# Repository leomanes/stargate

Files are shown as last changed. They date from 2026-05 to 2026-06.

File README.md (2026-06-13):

# Stargate MSX Compatible Computer

> [!NOTE]
>**Latest updates:**<br>
>- Version 2.1.3 released<br>
>  -- new onboard amp module+speaker connectors;<br>
>  -- Tang Nano PWM audio connected to the mixer.<br>
>- Kicad files available (Kicad v9.0.2) <br>

Stargate is an MSX compatible computer built using parts that are still available today.

Many original MSX parts are becoming harder to find, more expensive, or counterfeit. Stargate uses a hybrid approach where common parts remain original while rare or unreliable components are replaced with modern alternatives such as the Tang Nano 20K.

The board is a dual layer PCB using 74-series logic, an 8255 PPI, and a real PSG chip. Video is handled by a Tang Nano 20K running a V9958 compatible core. The Z80 is also implemented inside the FPGA.

If you have a soldering iron and some patience, you can probably put it together.

The machine is built around the **[Goauld SD project](https://github.com/jabadiagm/MSXgoauldSD_tn20k)** by Javier Abadia.

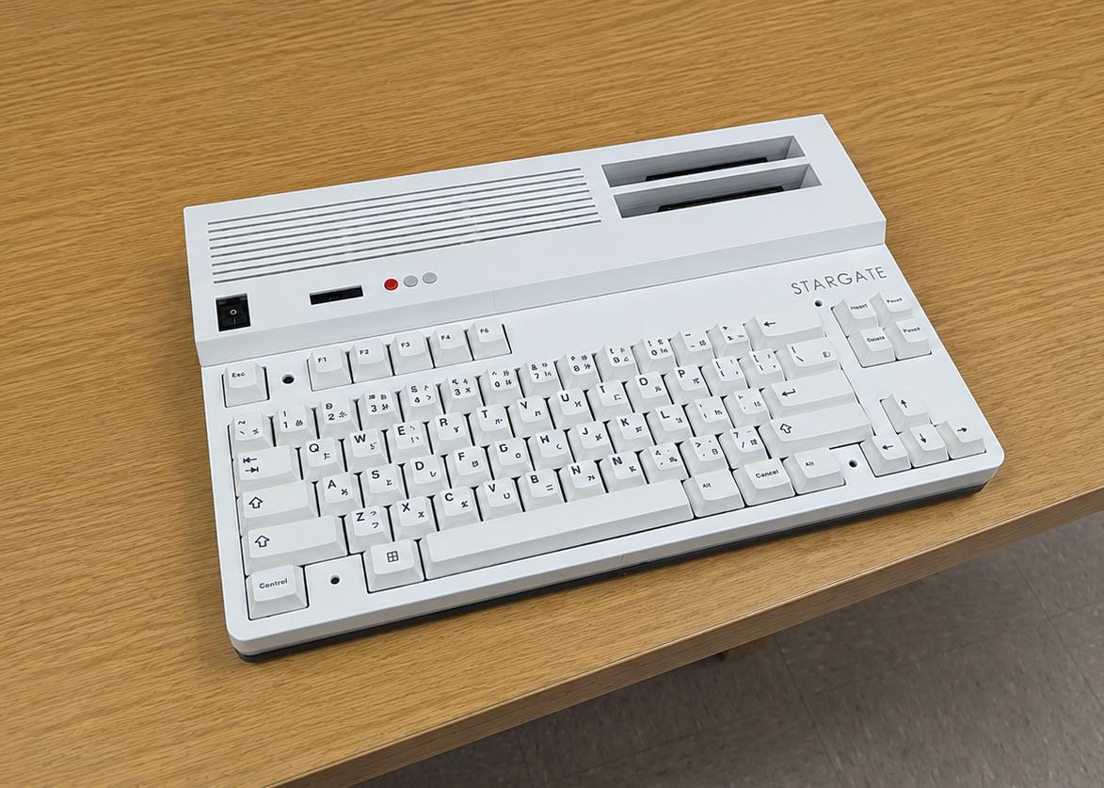
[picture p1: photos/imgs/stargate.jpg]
Stargate

## Selling Stargate

Stargate wasn't built to be a commercial product, but as an open source project, nothing stops you from using it that way. All I ask is that you don't modify the original files in any way.

Do not modify the original files in any way or form.

## Goauld SD project

https://github.com/jabadiagm/MSXgoauldSD_tn20k

## Goauld Core specs

- Z80
- V9958 compatible video with HDMI output
- MSX2+ BIOS
- SD card support with Nextor 2.1
- 4 MB mapper
- 2 MB MegaRAM SCC
- RTC
- PSG
- OPLL
- Kanji Level 1 and 2
- Wi-Fi support using ESP

## Stargate features

- Mechanical keyboard
- OLED display
- Overclocking up to 14 MHz (WIP)
- RGB LED effects
- On-board audio
- Audio output
- Reset button
- USB-C and barrel jack for power
- Two joystick ports
- Two cartridge slots
- USB network printing
- IoT Tasmota integration
- IoT TP-Link HS1xx outlet control

## WIP Daughter Board (Internal/External)

> [!NOTE]
> Additional features are provided through an optional daughter board.<bR>
> WIP (no release date yet).

**Ready:**

- USB printer support
- Ethernet connection
- Bluetooth joystick firmware
- RGB Gaming mode (LEDs react to RGB modded games)

**WIP:**

- Slot 2 expansion with custom cartridge
- USB flash drive support
- USB floppy support
- Fast Wi-Fi
- Bluetooth joystick software (extra buttons mapped to keyboard keys)

> [!NOTE]
> Stargate can be assembled without the extra features as a standard MSX compatible computer.

## GitHub

https://github.com/leomanes/stargate

> [!IMPORTANT]
> Project files will be made available when time permits.

## Open Source projects

- Javier Abadia, MSXgoauldSD_tn20k project — https://github.com/jabadiagm
- NataliaPC, MSXgoauld Settings Menu — https://github.com/nataliapc
- Skoti, JFF Computer — https://github.com/konkotgit
- Sergey Kiselev, Omega Keyboard — https://github.com/skiselev
- Oduvaldo (ducasp), UNAPI Driver — https://github.com/ducasp

## Other references

HARA, konamiman, antoniosi

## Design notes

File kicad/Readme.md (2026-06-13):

**Stargate_v2.1.3.zip**
Gerbers in /version v2.1.3 production/production

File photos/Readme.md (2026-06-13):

# Photos

<!-- Regenerate with: py gen_photos_readme.py -->

<table>
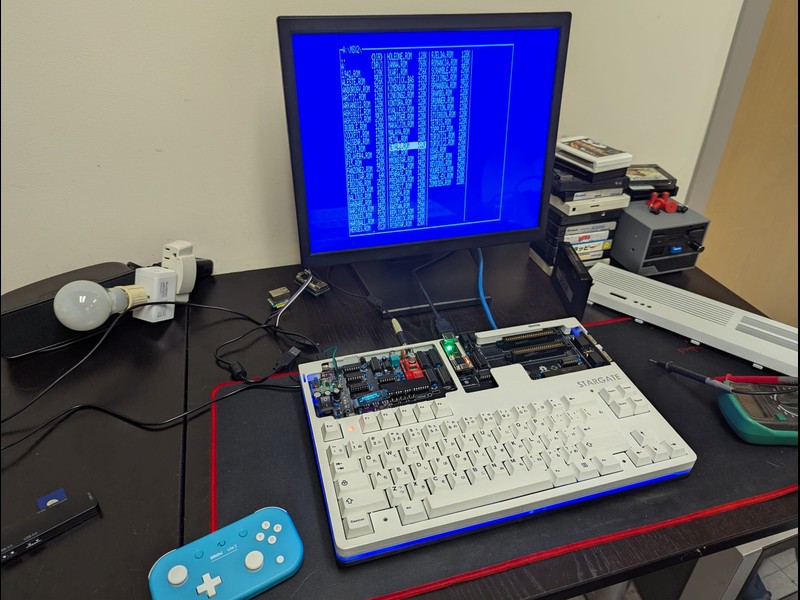
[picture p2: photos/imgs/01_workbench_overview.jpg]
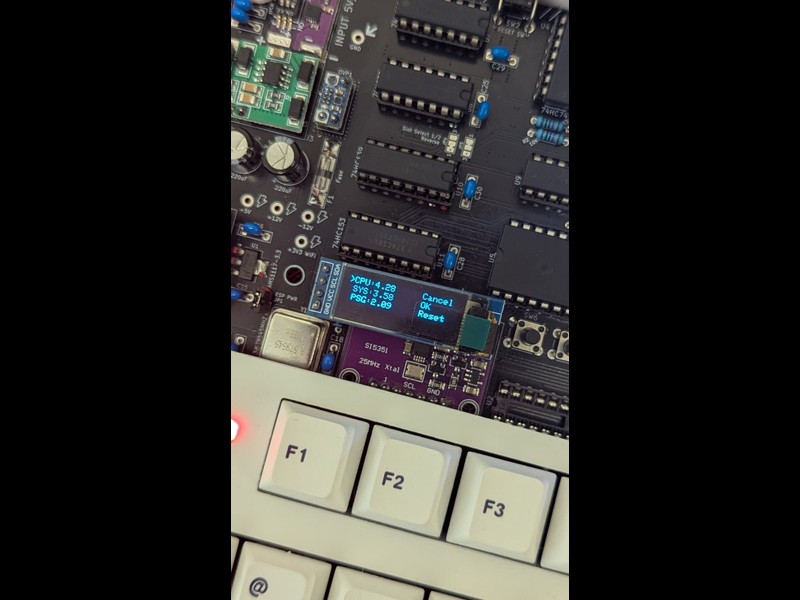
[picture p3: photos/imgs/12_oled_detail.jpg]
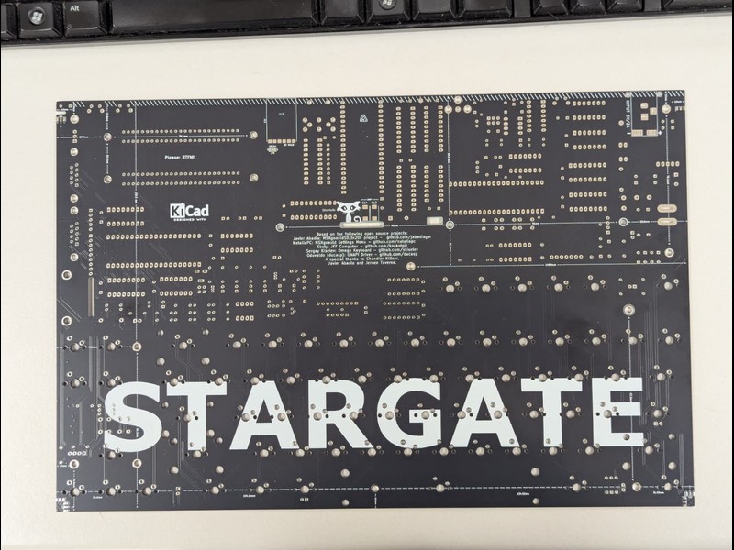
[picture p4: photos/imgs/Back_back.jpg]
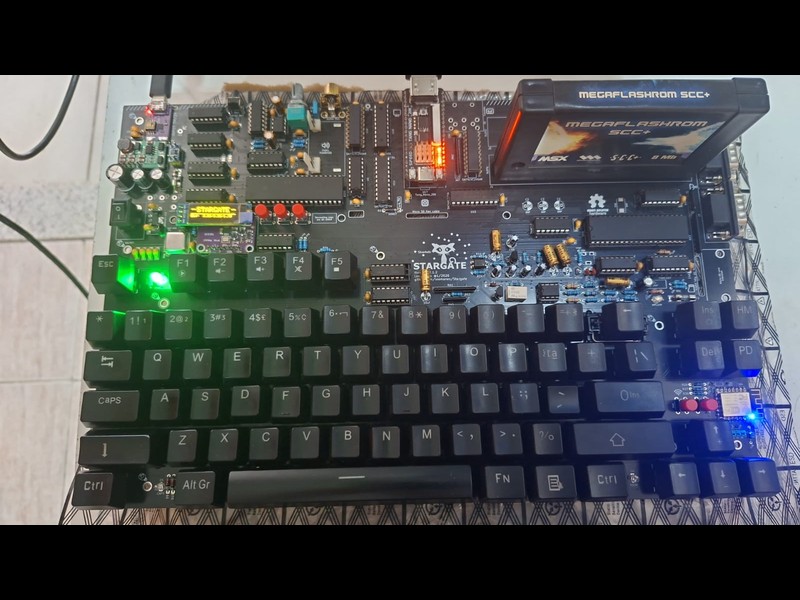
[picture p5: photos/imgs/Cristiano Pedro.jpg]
<tr><td align="center" valign="top"><br><sub>01_workbench_overview.jpg</sub></td><td align="center" valign="top"><br><sub>12_oled_detail.jpg</sub></td><td align="center" valign="top"><br><sub>Back_back.jpg</sub></td><td align="center" valign="top"><br><sub>Cristiano Pedro.jpg</sub></td></tr>
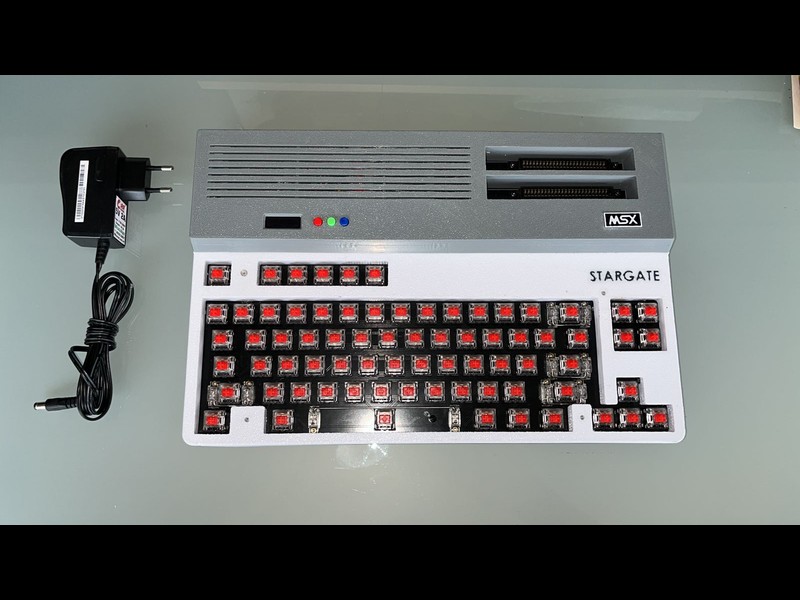
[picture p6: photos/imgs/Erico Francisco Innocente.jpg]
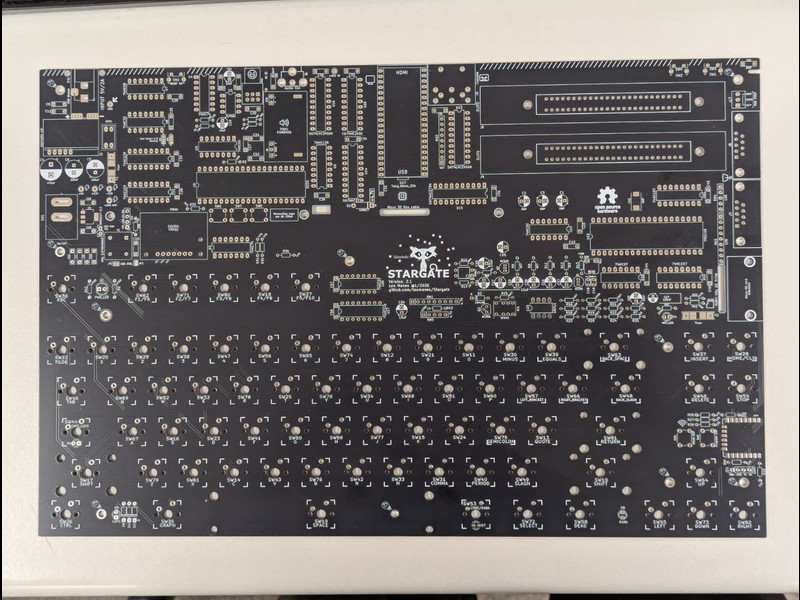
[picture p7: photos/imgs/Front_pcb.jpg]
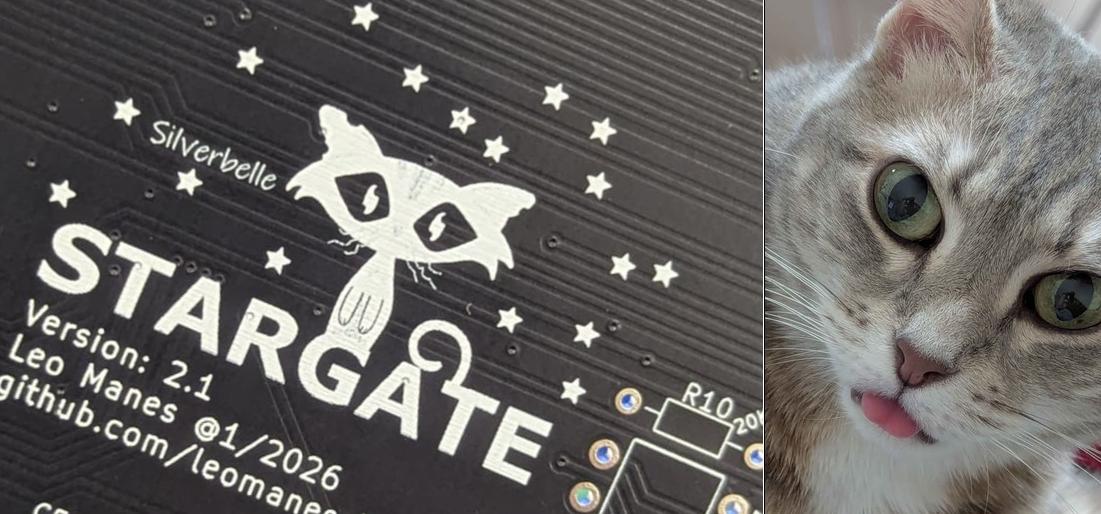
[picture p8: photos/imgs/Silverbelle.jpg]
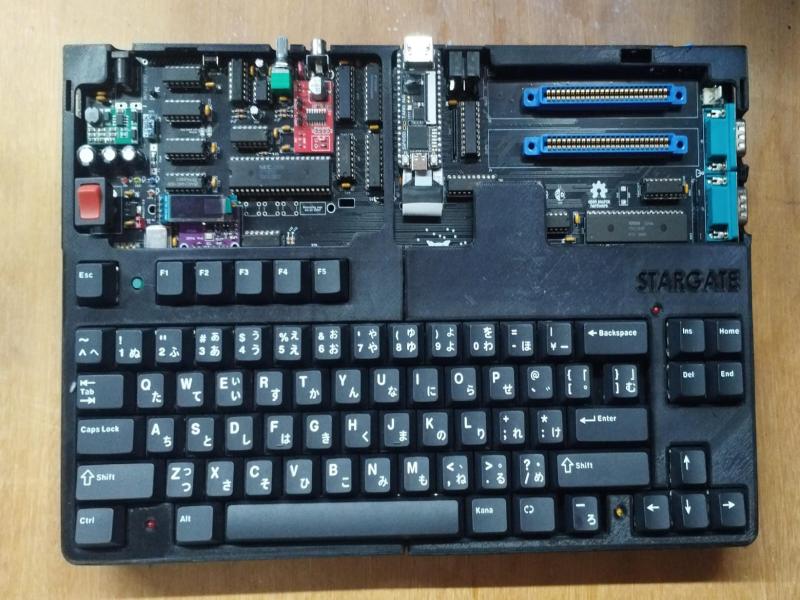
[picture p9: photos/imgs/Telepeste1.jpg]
<tr><td align="center" valign="top"><br><sub>Erico Francisco Innocente.jpg</sub></td><td align="center" valign="top"><br><sub>Front_pcb.jpg</sub></td><td align="center" valign="top"><br><sub>Silverbelle.jpg</sub></td><td align="center" valign="top"><br><sub>Telepeste1.jpg</sub></td></tr>
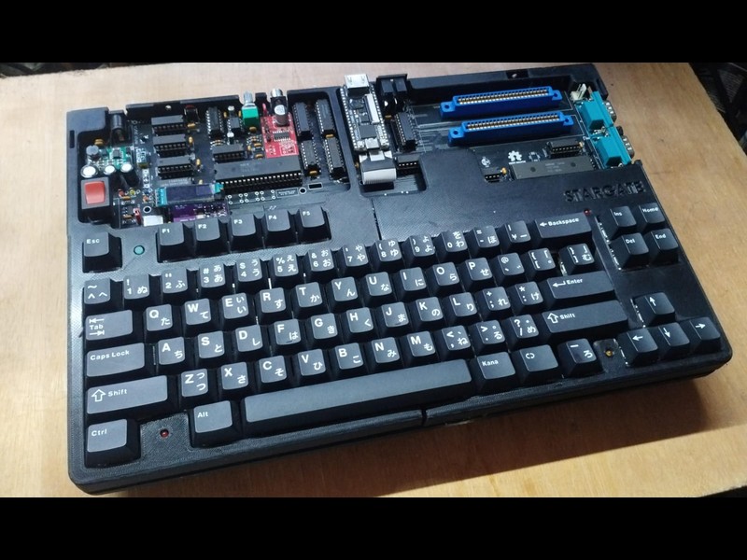
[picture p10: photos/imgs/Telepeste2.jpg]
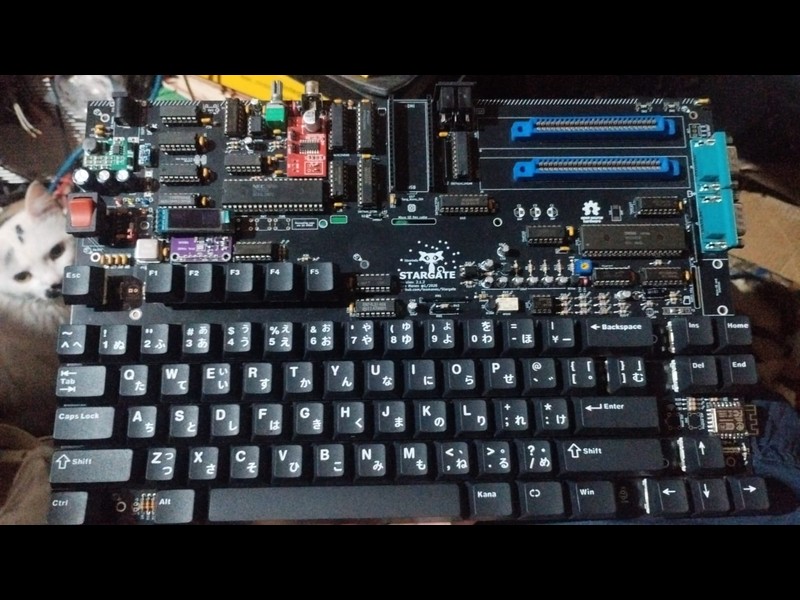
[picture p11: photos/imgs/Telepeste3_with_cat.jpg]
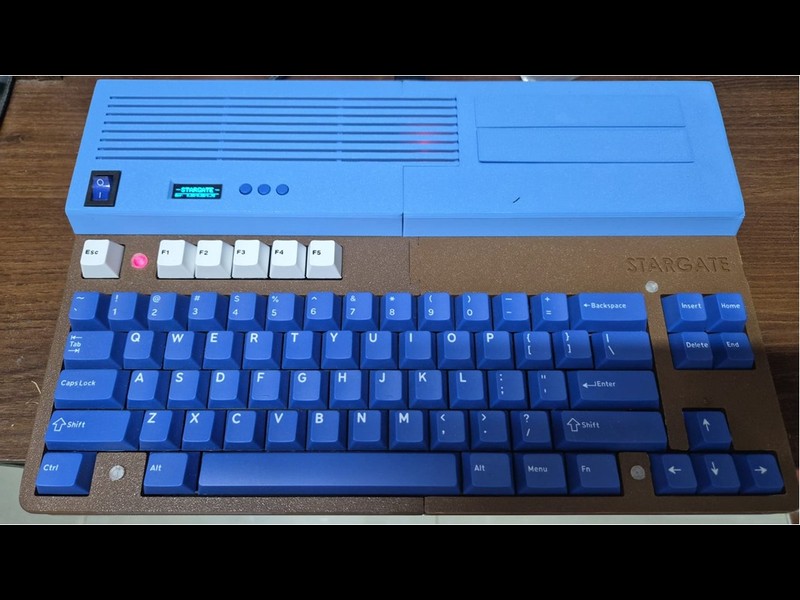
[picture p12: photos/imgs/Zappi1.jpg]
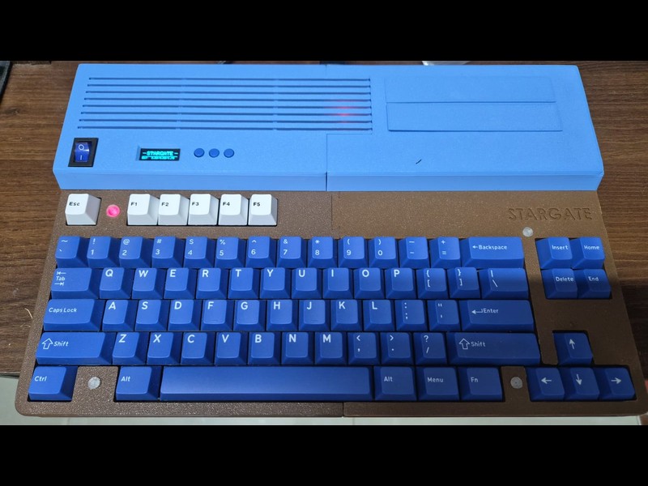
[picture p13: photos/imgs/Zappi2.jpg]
<tr><td align="center" valign="top"><br><sub>Telepeste2.jpg</sub></td><td align="center" valign="top"><br><sub>Telepeste3_with_cat.jpg</sub></td><td align="center" valign="top"><br><sub>Zappi1.jpg</sub></td><td align="center" valign="top"><br><sub>Zappi2.jpg</sub></td></tr>
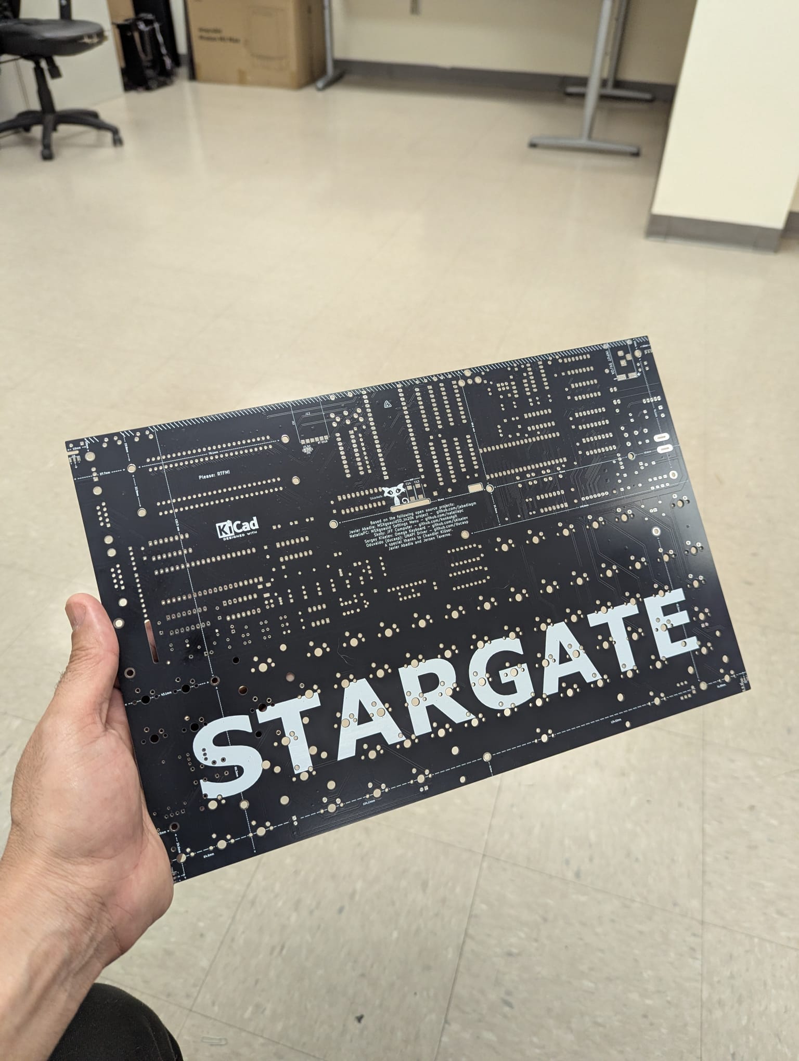
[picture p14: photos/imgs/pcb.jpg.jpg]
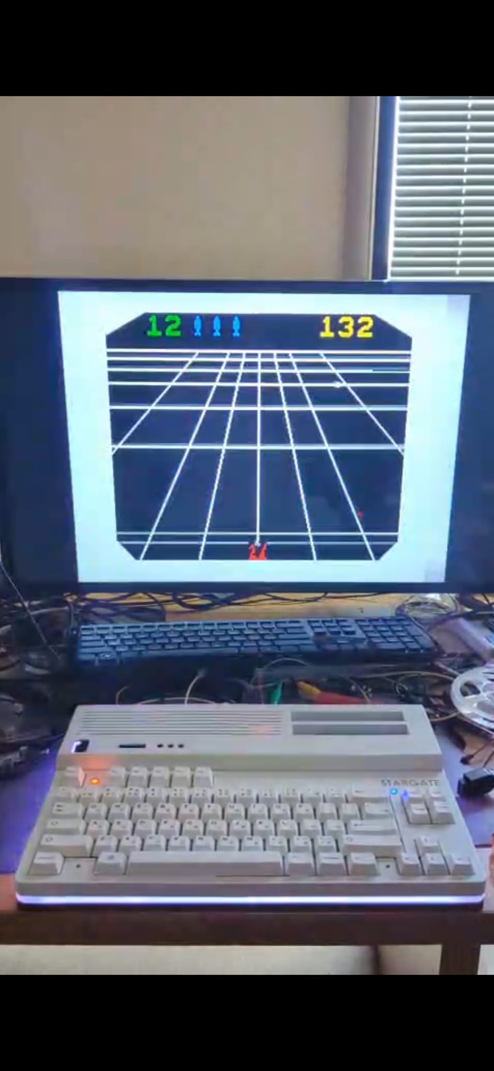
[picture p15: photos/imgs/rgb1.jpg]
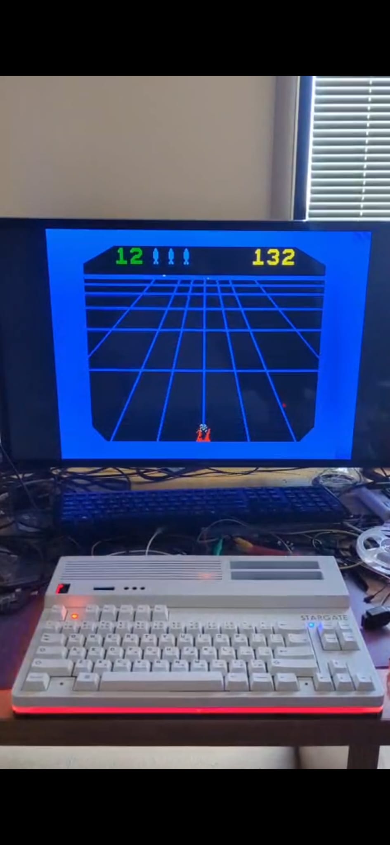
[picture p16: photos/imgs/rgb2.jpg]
<tr><td align="center" valign="top"><br><sub>pcb.jpg.jpg</sub></td><td align="center" valign="top"><br><sub>rgb1.jpg</sub></td><td align="center" valign="top"><br><sub>rgb2.jpg</sub></td><td align="center" valign="top"><br><sub>stargate.jpg</sub></td></tr>
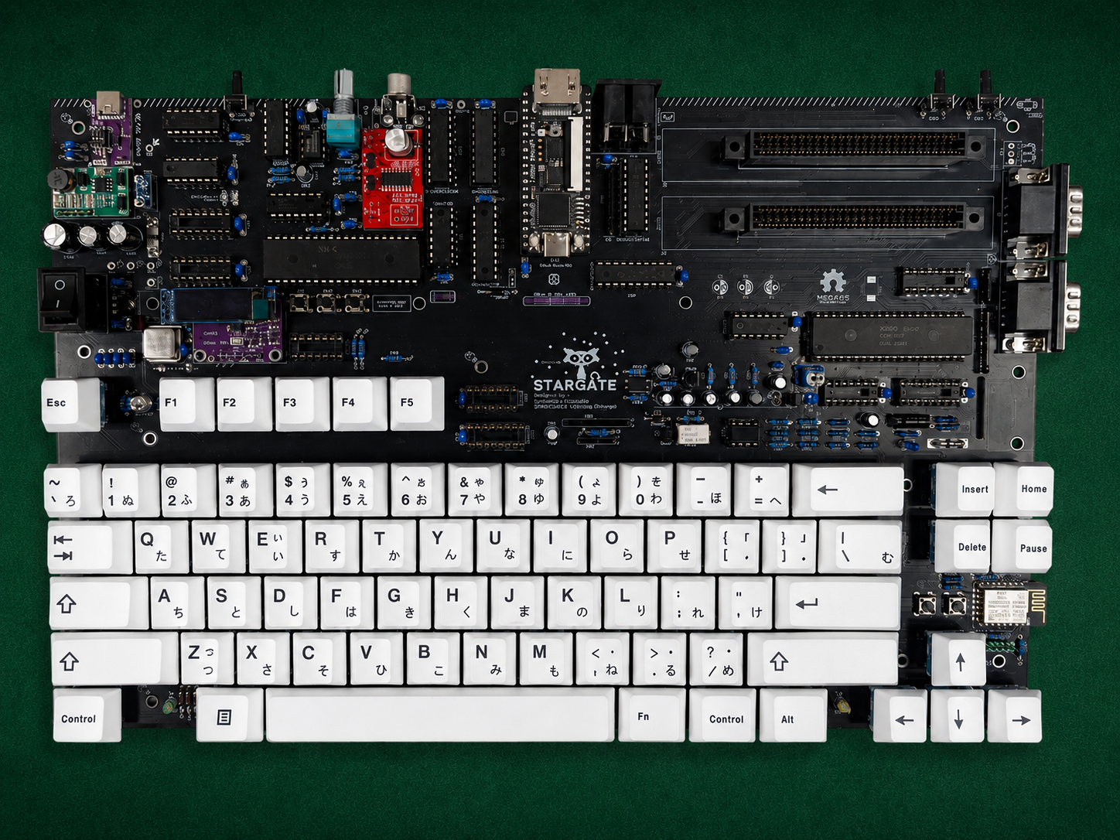
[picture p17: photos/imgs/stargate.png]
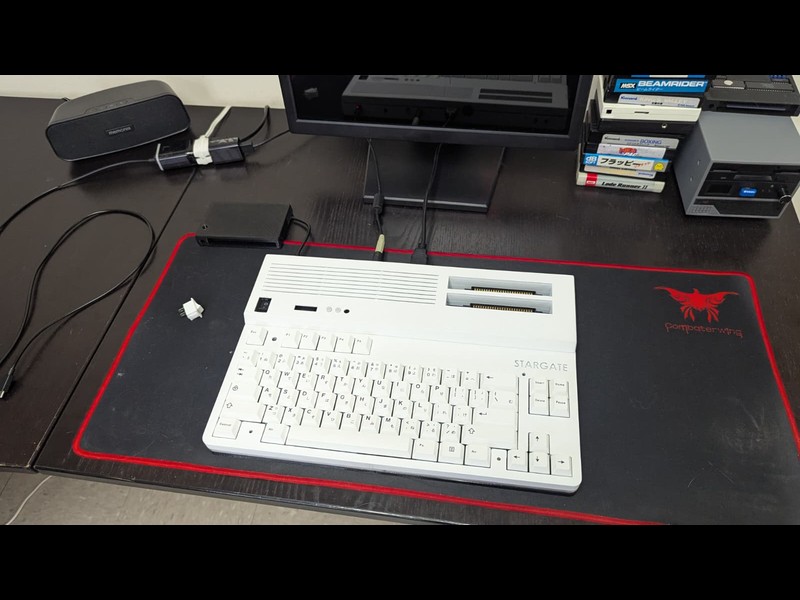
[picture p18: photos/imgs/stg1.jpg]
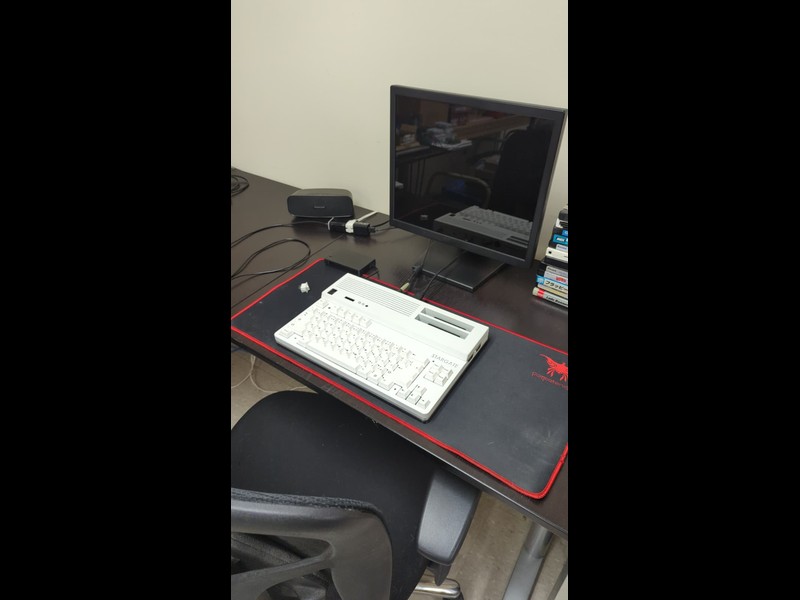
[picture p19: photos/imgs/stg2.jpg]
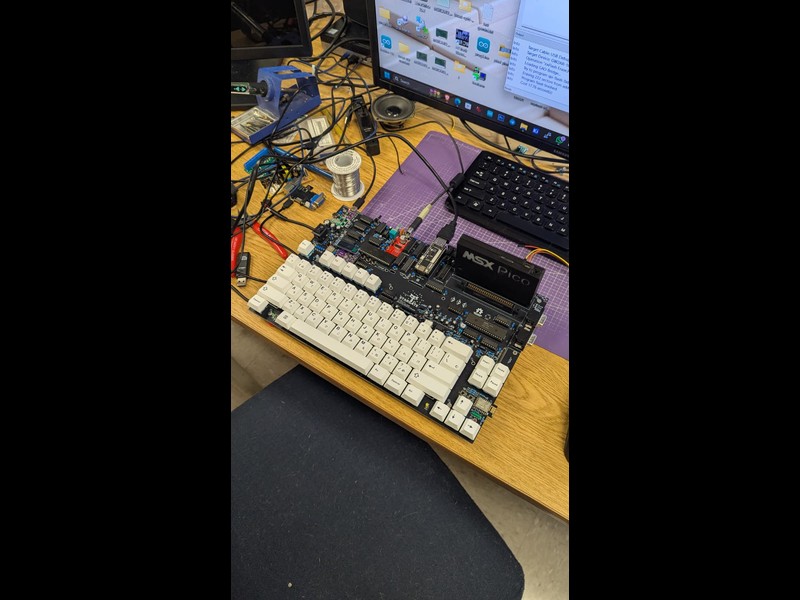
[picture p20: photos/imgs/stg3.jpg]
<tr><td align="center" valign="top"><br><sub>stargate.png</sub></td><td align="center" valign="top"><br><sub>stg1.jpg</sub></td><td align="center" valign="top"><br><sub>stg2.jpg</sub></td><td align="center" valign="top"><br><sub>stg3.jpg</sub></td></tr>
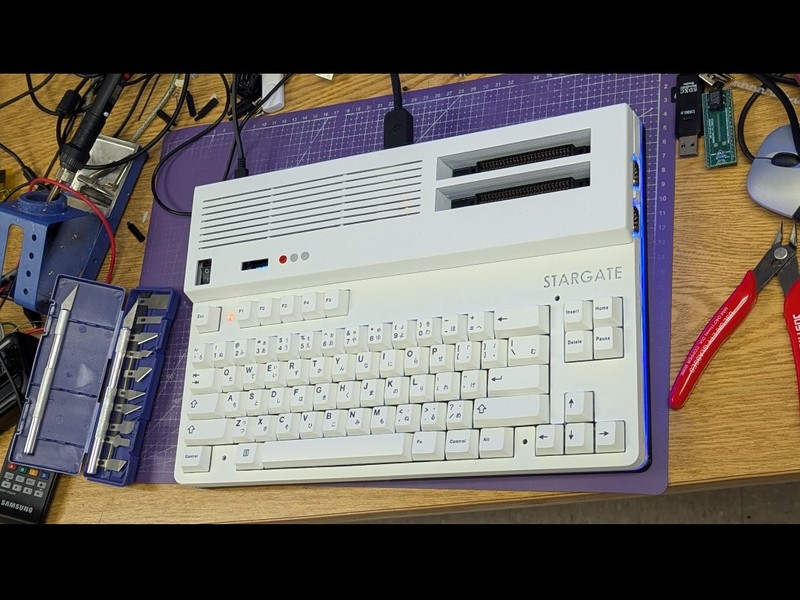
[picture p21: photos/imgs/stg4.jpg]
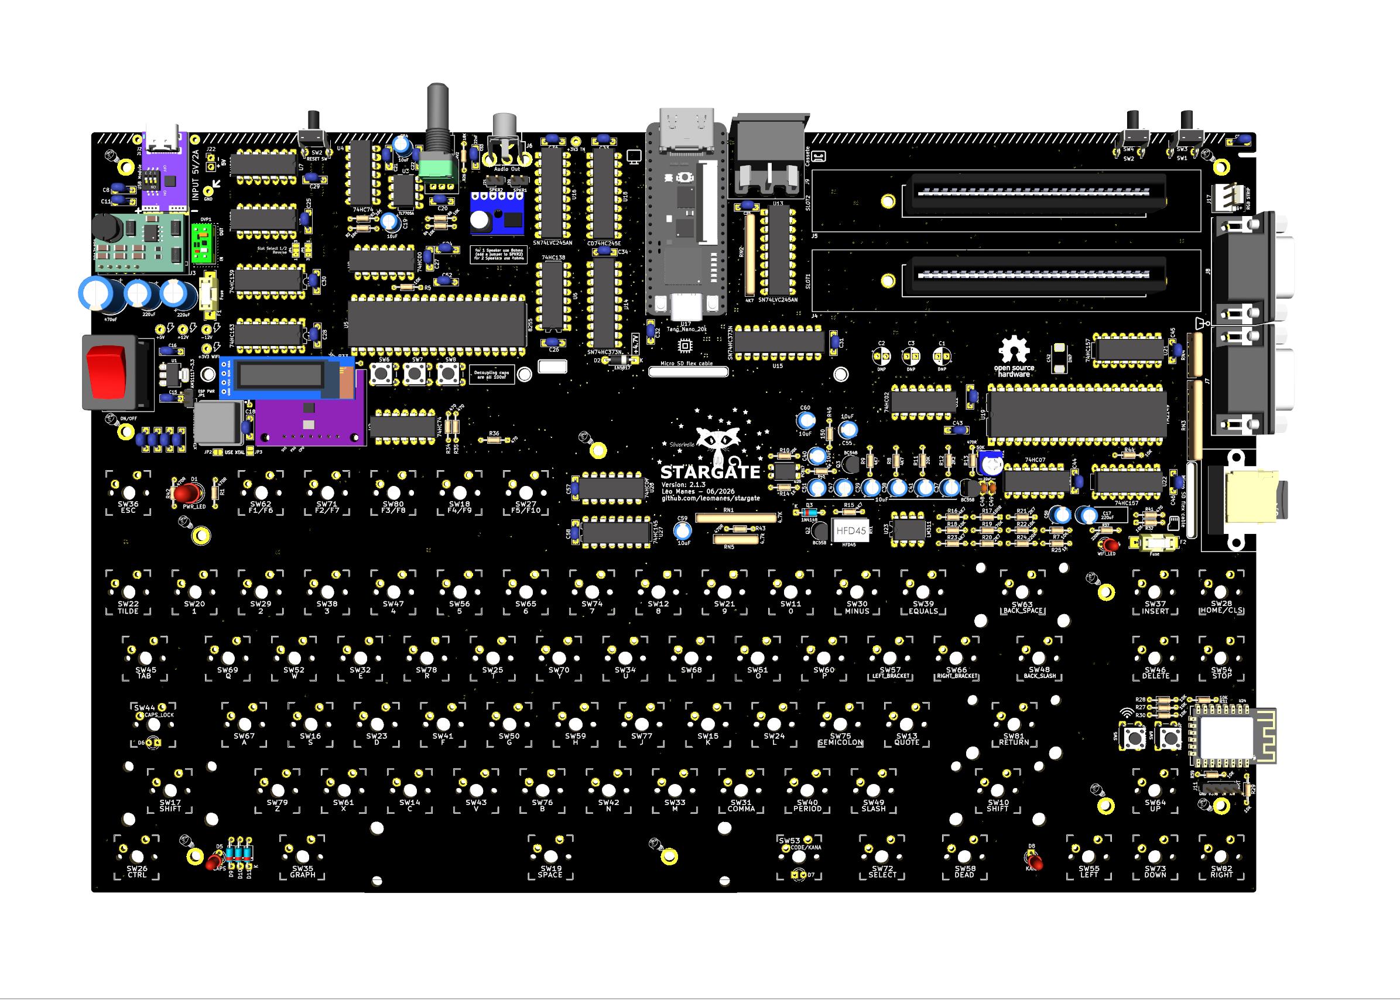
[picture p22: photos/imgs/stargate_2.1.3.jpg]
<tr><td align="center" valign="top"><br><sub>stg4.jpg</sub></td><td align="center" valign="top"><br><sub>stargate_2.1.3.jpg</sub></td></tr>
</table>

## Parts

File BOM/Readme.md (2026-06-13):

# Stargate Parts List & Links (V2.1.3)

> I have no idea if the links listed here will work, if the parts are from a reliable vendor or if they are of good quality. Please do your own research.

## Modules & Major Parts

| Reference | Qty | Value | Link example |
|---|---|---|---|
| Fuse | 1 | 1.5A | <https://www.aliexpress.us/item/2255801012350097.html> |
| Fuse | 1 | 0.5A | <https://www.aliexpress.us/item/2255801012350097.html> |
| Relay | 1 | HFD4-5 | <https://www.aliexpress.us/item/3256806642059309.html> |
| OLED Screen | 1 | SSD1306 128x32 | <https://www.aliexpress.us/item/3256810382441111.html> |
| DIN8 | 1 | 8 pins | <https://www.aliexpress.us/item/3256803009734845.html> |
| OVP | 1 | Overvoltage Protection 5V | <https://www.aliexpress.us/item/3256810199010529.html> |
| Clock Gen | 1 | SI5351 | <https://www.aliexpress.us/item/3256809498025225.html> |
| YM2149F | 1 | Yamaha audio chip (AY-3-8910 was not tested) | <https://www.aliexpress.us/item/3256805857392394.html> |
| 3.57MHz | 1 | oscilator module xtal | <https://www.aliexpress.us/item/2251832699611090.html> |
| dd1718pa | 1 | Buck module +-12V (NO PIN option) | <https://www.aliexpress.us/item/3256807659398693.html> |
| RGB strip | 1 | 5V (2.7mm), 1m | <https://www.aliexpress.us/item/3256806542970058.html> |
| Amplifier | 1 | Onboard Amp 5128 | <https://www.aliexpress.us/item/3256807058360209.html> |
| Potentiometer | 1 | Potentiomenter 47K/50K (mono or stereo) | <https://www.aliexpress.us/item/2251832675872559.html> |
| Tactile Switch angle | 3 | 6x6x15 (3 - back buttons) | <https://www.aliexpress.us/item/3256809907015472.html> |
| Tactile Switch | 3 | 6x6x13 (3 - oled buttons) | <https://www.aliexpress.us/item/3256805862813072.html> |
| Tactile Switch | 2 | 6x6x4.3 (2 - ESP buttons) | <https://www.aliexpress.us/item/3256805862813072.html> |
| MCU | 1 | ESP12F (the older ESP12E also works) | <https://www.aliexpress.us/item/3256805905748177.html> |
| ams1117-3v3 | 1 | 3.3V regulator SMD | <https://www.aliexpress.us/item/3256802301389307.html> |
| ON/OFF | 1 | switch (15x21) | <https://www.aliexpress.us/item/3256807758713102.html> |
| PC817 | 1 | optocoupler | <https://www.aliexpress.us/item/3256808061802481.html> |
| Micro SD flex | 1 | Extension 25cm | <https://www.aliexpress.us/item/3256806940297869.html> |
| M18 BT | 1 | BT Module | <https://www.aliexpress.us/item/3256809630730449.html> |

### Others

| Reference | Value | Link example |
|---|---|---|
| Keycaps set | Option "Black JIS" (two horizontal ENTER keys) | <https://www.aliexpress.us/item/3256809277322870.html> |
| Keycaps set | Japanese Option | <https://www.aliexpress.us/item/3256806285170564.html> |
| Keyboard stabilizers | 4 pieces (clip-on) | <https://www.aliexpress.us/item/3256801500004993.html> |
| Keyboard stabilizers | 4 pieces (with screws, safer) - black color | <https://www.aliexpress.us/item/3256807050530252.html> |
| Switches kit | MX 5 pins | |
| Switches caps | mixed colors | <https://www.aliexpress.us/item/3256809614465685.html> |

## Passive Components

- **Resistors:** 1/4W
- **Capacitors:** C5–C6 ≥ 25V and the rest is ≥ 16V

| Reference | Qty | Value | Footprint |
|---|---|---|---|
| C1, C2, C3 | 3 | DNP | NA |
| C4 | 1 | 470uF | Capacitor Electrolytic: lead space 5mm / Height: <10mm |
| C5, C6 | 2 | 220uF | Capacitor Electrolytic: lead space 3.5mm / Height: <10mm |
| C7, C8, C9, C10, C11, C12, C15, C16, C18, C20, C21, C22, C23, C24, C25, C26, C27, C28, C29, C30, C36, C43, C44, C45, C46, C52, C57, C58, C31, C32, C33, C34, C35 | 28 | 100nF | Capacitor Tantalum or Multilayer: lead space 5mm |
| C13, C14, C42 | 3 | DNP | NA |
| C17 | 1 | 220uF | Capacitor Electrolytic: lead space 2.5mm / Height: <8mm |
| C19, C37, C38, C39, C40, C41, C47, C50, C51, C54, C55, C59 | 12 | 10uF | Capacitor Electrolytic: lead space 2.5mm / Height: <8mm |
| C48, C49 | 2 | 22nF | Capacitor Tantalum or Multilayer: lead space 2.5mm |
| C53 | 1 | up to 22nF | Capacitor Tantalum or Multilayer: lead space 5mm (internal amp - high frequency cut) |
| C56 | 1 | DNP | - |
| R1, R13, R42, R43, R34, R35, R36, R41 | 4 | 470R | Resistor 1/4w 7.62mm_Horizontal |
| R2, R3, R4, R5, R6, R7, R18, R22, R27, R28, R29, R30, R31, R32, R39, R44 | 16 | 10K | Resistor 1/4w 7.62mm_Horizontal |
| R8, R9, R15, R16, R23, R26 | 6 | 4K7 | Resistor 1/4w 7.62mm_Horizontal |
| R10, R11 | 2 | 20K | Resistor 1/4w 7.62mm_Horizontal |
| R12 | 1 | 2K2 | Resistor 1/4w 7.62mm_Horizontal |
| R14, R25, R40 | 3 | 1K | Resistor 1/4w 7.62mm_Horizontal |
| R17 | 1 | 100R | Resistor 1/4w 7.62mm_Horizontal |
| R19 | 1 | 470K | Resistor 1/4w 7.62mm_Horizontal |
| R20, R21 | 2 | 2K7 | Resistor 1/4w 7.62mm_Horizontal |
| R24 | 1 | 220K | Resistor 1/4w 7.62mm_Horizontal |
| R26 | 1 | 18K | Resistor 1/4w 7.62mm_Horizontal |
| R33 | 1 | 3K3 | Resistor 1/4w 7.62mm_Horizontal |
| R34, R35, R36, R41 | 4 | 470R | Resistor 1/4w 7.62mm_Horizontal |
| R37 | 1 | 220R | Resistor 1/4w 7.62mm_Horizontal |
| R38 | 1 | 1M | Resistor 1/4w 7.62mm_Horizontal |

## Integrated Circuits

| IC Reference | Qty | Value | Alternates |
|---|---|---|---|
| U1 | 1 | AMS1117-3.3 | LM1117-3.3 |
| U10 | 1 | 74HC139 | LS/HCT |
| U11 | 1 | 74HC153 | LS/HCT |
| U12 | 1 | 74HC02 | LS/HCT |
| U13, U16 | 2 | 74LVC245 | - |
| U14, U15 | 2 | 74HC373 | HCT |
| U17 | 1 | Tang_Nano_20k | NA |
| U18 | 1 | 74HC245 | - |
| U19 | 1 | YM2149 | |
| U2, U4 | 2 | 74HC74 | LS/HCT |
| U20, U26 | 2 | 74LS07 | - |
| U21, U22 | 2 | 74HC157 | LS/HCT |
| U23 | 1 | LM311 | P or N |
| U24 | 1 | ESP-12F | |
| U25 | 1 | PC817 | |
| U27 | 1 | 74LS145 | - |
| U3 | 1 | TL7705A | |
| U5 | 1 | 8255 | |
| U6 | 1 | 74HC138 | LS/HCT |
| U7 | 1 | 74HC08 | LS/HCT |
| U8 | 1 | 74HC32 | LS/HCT |
| U9 | 1 | 74HC00 | LS/HCT |

## Powering Your Stargate

USB-C or Barrel Jack (**USB-C HIGHLY recommended**).

### Barrel Jack option

> A low quality power supply can cause freezes and other unknown behaviours.

| Reference | Value | Link example |
|---|---|---|
| Jack connector | Barrel jack 5.5mm (with 2.1mm hole) | <https://www.aliexpress.us/item/3256803142763786.html> |
| Power adaptor | 5V-2A (3A recommended) 5.5mm / center positive (with 2.1mm hole) | <https://www.aliexpress.us/item/3256803596239663.html> |
| Power adaptor (alt) | — | <https://www.aliexpress.us/item/3256808282333732.html> |
| Power adaptor (alt) | — | <https://www.aliexpress.us/item/3256808943863317.html> |

### USB-C option

| Reference | Value | Link example |
|---|---|---|
| USB-C power brick | >10W (2A) [15W (3A) recommended] any type is ok (common or PD) | Try your phone charger |
| USB-C power | USB Decoy (or barrel jack optional) | <https://www.aliexpress.us/item/3256808182904772.html> |

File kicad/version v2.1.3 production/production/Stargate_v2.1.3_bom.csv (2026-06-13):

Designator | Footprint | Quantity | Value | LCSC Part #
AMP1 | Amp5128 | 1 | 5128
C1, C2, C3 | CP_Radial_D5.0mm_P2.50mm | 3 | DNP
C10, C11, C12, C18, C20, C21, C22, C23, C24, C25, C26, C27, C28, C29, C30, C31, C32, C33, C34, C35, C36, C43, C44, C45, C46, C52, C57, C58, C7, C8, C9 | CP_P5.00mm | 31 | 100nF
C13, C14, C42 | CP_EIA-7343-31_Kemet-D | 3 | DNP
C15, C16 | CP_P5.00mm | 2 | 100nF | C14663
C17 | CP_Radial_D5.0mm_P2.50mm | 1 | 220uF | C59461
C19, C37, C38, C39, C40, C41, C47, C50, C51, C54, C55, C59, C60 | CP_Radial_D5.0mm_P2.50mm | 13 | 10uF
C4 | CP_Radial_D10.0mm_P5.00mm | 1 | 470uF
C48, C49 | C_Disc_D3.0mm_W2.0mm_P2.50mm | 2 | 22nF
C5, C6 | CP_Radial_D8.0mm_P3.50mm | 2 | 220uF
C53 | CP_P5.00mm | 1 | 22nF
C56 | CP_P5.00mm | 1 | DNP | C14663
D1 | LED_D5.0mm | 1 | PWR_LED
D10, D11, D3, D9 | D_DO-35_SOD27_P7.62mm_Horizontal | 4 | 1N4148
D2 | D_DO-41_SOD81_P7.62mm_Horizontal | 1 | 1N5817
D4 | LED_D3.0mm | 1 | WIFI_LED | C2290
D5, D6 | LED_D3.0mm | 2 | CAPS
D7, D8 | LED_D3.0mm | 2 | KANA
F1, F2 | THT+SMD(Fuse) | 2 | Fuse
FREQ1 | si5351 | 1 | SI5351
HOLE1, HOLE12, HOLE2, HOLE3, HOLE4, HOLE5, HOLE6, HOLE7, HOLE8, HOLE9 | MountingHole_3mm_Pad_TopBottom_new | 10 | HOLE
HOLE10, HOLE11 | MountingHole_2mm_Pad_TopBottom_new | 2 | HOLE
J1 | BarrelJack_Horizontal | 1 | Barrel_Jack
J10 | PinHeader_1x04_P2.54mm_Vertical | 1 | I2C
J11 | PinHeader_1x04_P2.54mm_Vertical | 1 | UART
J12 | MH-M18 | 1 | BT MX18
J13, J15, J19 | ledstrip_end | 3 | RGB Strip
J14, J16, J18 | ledstrip | 3 | RGB Strip
J17 | FanPinHeader_1x03_P2.54mm_Vertical | 1 | RGB out
J2 | USB-C Decoy | 1 | USB Module
J20 | PinHeader_1x02_P2.54mm_Vertical | 1 | SPKR1
J21 | PinHeader_1x02_P2.54mm_Vertical | 1 | SPKR2
J22 | PinHeader_1x02_P2.54mm_Vertical | 1 | Conn_5V
J3 | dd1718pa_down | 1 | DD1718PA 12V
J4 | Conn_Edge_50P | 1 | SLOT1
J5 | Conn_Edge_50P | 1 | SLOT2
J6 | Conn_RCA_Right | 1 | Audio Out
J7 | Conn_Dsub_DE9M | 1 | Joystick1
J8 | Conn_Dsub_DE9M | 1 | Joystick2
J9 | DIN8 | 1 | DIN-8
JP1 | PinHeader_1x02_P2.54mm_Vertical | 1 | ESP PWR
JP2 | SolderJumper-2_P1.3mm_Open_Pad1.0x1.5mm | 1 | XTAL ON
JP3 | SolderJumper-2_P1.3mm_Open_Pad1.0x1.5mm | 1 | XTAL>SYS
JP7 | SolderJumper-2_P1.3mm_Open_Pad1.0x1.5mm | 1 | 50on
OVP1 | OVP | 1 | 5V
Q1, Q2 | TO-92 | 2 | BC558
Q3 | TO-92 | 1 | BC548
R1, R13, R42, R43 | R_Axial_DIN0204_L3.6mm_D1.6mm_P7.62mm_Horizontal | 4 | 470R
R10, R11 | R_Axial_DIN0204_L3.6mm_D1.6mm_P7.62mm_Horizontal | 2 | 20K
R12 | R_Axial_DIN0204_L3.6mm_D1.6mm_P7.62mm_Horizontal | 1 | 2K2
R14, R25, R40 | R_Axial_DIN0204_L3.6mm_D1.6mm_P7.62mm_Horizontal | 3 | 1K
R15, R16, R23, R8, R9 | R_Axial_DIN0204_L3.6mm_D1.6mm_P7.62mm_Horizontal | 5 | 4K7
R17 | R_Axial_DIN0204_L3.6mm_D1.6mm_P7.62mm_Horizontal | 1 | 100R
R18, R2, R22, R3, R4, R44, R5, R6, R7 | R_Axial_DIN0204_L3.6mm_D1.6mm_P7.62mm_Horizontal | 9 | 10K
R19 | R_Axial_DIN0204_L3.6mm_D1.6mm_P7.62mm_Horizontal | 1 | 470K
R20, R21 | R_Axial_DIN0204_L3.6mm_D1.6mm_P7.62mm_Horizontal | 2 | 2K7
R24 | R_Axial_DIN0204_L3.6mm_D1.6mm_P7.62mm_Horizontal | 1 | 220K
R26 | R_Axial_DIN0204_L3.6mm_D1.6mm_P7.62mm_Horizontal | 1 | 18K
R27, R28, R29, R30, R31, R32, R39 | R_Axial_DIN0204_L3.6mm_D1.6mm_P7.62mm_Horizontal | 7 | 10K | C11702
R33 | R_Axial_DIN0204_L3.6mm_D1.6mm_P7.62mm_Horizontal | 1 | 3K3 | C11702
R34, R35, R36 | R_Axial_DIN0204_L3.6mm_D1.6mm_P7.62mm_Horizontal | 3 | 470 | C11702
R37 | R_Axial_DIN0204_L3.6mm_D1.6mm_P7.62mm_Horizontal | 1 | 220R | C11702
R38 | R_Axial_DIN0204_L3.6mm_D1.6mm_P7.62mm_Horizontal | 1 | 1M | C11702
R41 | R_Axial_DIN0204_L3.6mm_D1.6mm_P7.62mm_Horizontal | 1 | 470
R45 | R_Axial_DIN0204_L3.6mm_D1.6mm_P7.62mm_Horizontal | 1 | 150
RN1 | R_Array_SIP9 | 1 | 4.7K
RN2 | R_Array_SIP9 | 1 | 4K7
RN3 | R_Array_SIP9 | 1 | 10K
RN4 | R_Array_SIP5 | 1 | 10K
RN5 | R_Array_SIP5 | 1 | 4.7k
RV1 | TrimPotLargeHole | 1 | 50K
RV2 | Potentiometer_Alps_RK097_Dual_Horizontal | 1 | Dual Pot
RY1 | HFD45 | 1 | HFD45
SW1 | SW_RF1-1A-DC-2-R-1 | 1 | ON/OFF
SW10 | CHERRY_PCB_275H | 1 | SHIFT
SW11 | CHERRY_PCB_100H | 1 | 0
SW12 | CHERRY_PCB_100H | 1 | 8
SW13 | CHERRY_PCB_100H | 1 | QUOTE
SW14 | CHERRY_PCB_100H | 1 | C
SW15 | CHERRY_PCB_100H | 1 | K
SW16 | CHERRY_PCB_100H | 1 | S
SW17 | CHERRY_PCB_225H | 1 | SHIFT
SW18 | CHERRY_PCB_100H | 1 | F4/F9
SW19 | CHERRY_PCB_625H | 1 | SPACE
SW2 | SW_Tactile_SPST_Angled_PTS645Vx83-2LFS | 1 | RESET SW
SW20 | CHERRY_PCB_100H | 1 | 1
SW21 | CHERRY_PCB_100H | 1 | 9
SW22 | CHERRY_PCB_100H | 1 | TILDE
SW23 | CHERRY_PCB_100H | 1 | D
SW24 | CHERRY_PCB_100H | 1 | L
SW25 | CHERRY_PCB_100H | 1 | T
SW26 | CHERRY_PCB_125H | 1 | CTRL
SW27 | CHERRY_PCB_100H | 1 | F5/F10
SW28 | CHERRY_PCB_100H | 1 | HOME/CLS
SW29 | CHERRY_PCB_100H | 1 | 2
SW3 | SW_Tactile_SPST_Angled_PTS645Vx83-2LFS | 1 | SW1
SW30 | CHERRY_PCB_100H | 1 | MINUS
SW31 | CHERRY_PCB_100H | 1 | COMMA
SW32 | CHERRY_PCB_100H | 1 | E
SW33 | CHERRY_PCB_100H | 1 | M
SW34 | CHERRY_PCB_100H | 1 | U
SW35 | CHERRY_PCB_125H | 1 | GRAPH
SW36 | CHERRY_PCB_100H | 1 | ESC
SW37 | CHERRY_PCB_100H | 1 | INSERT
SW38 | CHERRY_PCB_100H | 1 | 3
SW39 | CHERRY_PCB_100H | 1 | EQUALS
SW4 | SW_Tactile_SPST_Angled_PTS645Vx83-2LFS | 1 | SW2
SW40 | CHERRY_PCB_100H | 1 | PERIOD
SW41 | CHERRY_PCB_100H | 1 | F
SW42 | CHERRY_PCB_100H | 1 | N
SW43 | CHERRY_PCB_100H | 1 | V
SW44 | CHERRY_PCB_175H | 1 | CAPS_LOCK
SW45 | CHERRY_PCB_150H | 1 | TAB
SW46 | CHERRY_PCB_100H | 1 | DELETE
SW47 | CHERRY_PCB_100H | 1 | 4
SW48 | CHERRY_PCB_150H | 1 | BACK_SLASH
SW49 | CHERRY_PCB_100H | 1 | SLASH
SW5 | SW_PUSH_6mm | 1 | Reset ESP
SW50 | CHERRY_PCB_100H | 1 | G
SW51 | CHERRY_PCB_100H | 1 | O
SW52 | CHERRY_PCB_100H | 1 | W
SW53 | CHERRY_PCB_125H | 1 | CODE/KANA
SW54 | CHERRY_PCB_100H | 1 | STOP
SW55 | CHERRY_PCB_100H | 1 | LEFT
SW56 | CHERRY_PCB_100H | 1 | 5
SW57 | CHERRY_PCB_100H | 1 | LEFT_BRACKET
SW58 | CHERRY_PCB_125H | 1 | DEAD
SW59 | CHERRY_PCB_100H | 1 | H
SW6 | SW_PUSH_6mm | 1 | UP
SW60 | CHERRY_PCB_100H | 1 | P
SW61 | CHERRY_PCB_100H | 1 | X
SW62 | CHERRY_PCB_100H | 1 | F1/F6
SW63 | CHERRY_PCB_200H | 1 | BACK_SPACE
SW64 | CHERRY_PCB_100H | 1 | UP
SW65 | CHERRY_PCB_100H | 1 | 6
SW66 | CHERRY_PCB_100H | 1 | RIGHT_BRACKET
SW67 | CHERRY_PCB_100H | 1 | A
SW68 | CHERRY_PCB_100H | 1 | I
SW69 | CHERRY_PCB_100H | 1 | Q
SW7 | SW_PUSH_6mm | 1 | DOWN
SW70 | CHERRY_PCB_100H | 1 | Y
SW71 | CHERRY_PCB_100H | 1 | F2/F7
SW72 | CHERRY_PCB_125H | 1 | SELECT
SW73 | CHERRY_PCB_100H | 1 | DOWN
SW74 | CHERRY_PCB_100H | 1 | 7
SW75 | CHERRY_PCB_100H | 1 | SEMICOLON
SW76 | CHERRY_PCB_100H | 1 | B
SW77 | CHERRY_PCB_100H | 1 | J
SW78 | CHERRY_PCB_100H | 1 | R
SW79 | CHERRY_PCB_100H | 1 | Z
SW8 | SW_PUSH_6mm | 1 | SELECT
SW80 | CHERRY_PCB_100H | 1 | F3/F8
SW81 | CHERRY_PCB_225H | 1 | RETURN
SW82 | CHERRY_PCB_100H | 1 | RIGHT
SW9 | SW_PUSH_6mm | 1 | Program ESP
TP1 | TestPoint_THTPad_D2.5mm_Drill1.2mm | 1 | GND
TP2 | TestPoint_THTPad_D2.5mm_Drill1.2mm | 1 | +3V3 TN
TP3 | TestPoint_THTPad_D2.5mm_Drill1.2mm | 1 | +3V3 WiFi
TP4 | TestPoint_THTPad_D2.5mm_Drill1.2mm | 1 | -12V
TP5 | TestPoint_THTPad_D2.5mm_Drill1.2mm | 1 | +12V
TP6 | TestPoint_THTPad_D2.5mm_Drill1.2mm | 1 | +5V
U1 | SOT-223-3_TabPin2 | 1 | AMS1117-3.3
U10 | DIP-16_W7.62mm_LongPads | 1 | 74HC139
U11 | DIP-16_W7.62mm_LongPads | 1 | 74HC153
U12 | DIP-14_W7.62mm_LongPads | 1 | 74HC02
U13, U16 | DIP-20_W7.62mm_LongPads | 2 | SN74LVC245AN
U14, U15 | DIP-20_W7.62mm_LongPads | 2 | SN74HC373N
U17 | Tang_Nano_20k | 1 | Tang_Nano_20k
U18 | DIP-20_W7.62mm_LongPads | 1 | CD74HC245E
U19 | DIP-40_W15.24mm_LongPads | 1 | YM2149
U2, U4 | DIP-14_W7.62mm_LongPads | 2 | 74HC74
U20 | DIP-14_W7.62mm_LongPads | 1 | 74HC07
U21, U22 | DIP-16_W7.62mm_LongPads | 2 | 74HC157
U23 | DIP-8_W7.62mm_LongPads | 1 | LM311
U24 | ESP-12F | 1 | ESP-12F
U25 | DIP-4_W7.62mm | 1 | PC817
U26 | DIP-14_W7.62mm | 1 | 74HC07
U27 | DIP-16_W7.62mm | 1 | 74HC145
U3 | DIP-8_W7.62mm_LongPads | 1 | TL7705A
U5 | DIP-40_W15.24mm_LongPads | 1 | 8255
U6 | DIP-16_W7.62mm_LongPads | 1 | 74HC138
U7 | DIP-14_W7.62mm_LongPads | 1 | 74HC08
U8 | DIP-14_W7.62mm_LongPads | 1 | 74HC32
U9 | DIP-14_W7.62mm_LongPads | 1 | 74HC00
Y1 | Oscillator_DIP-8 | 1 | 3.579545MHZ

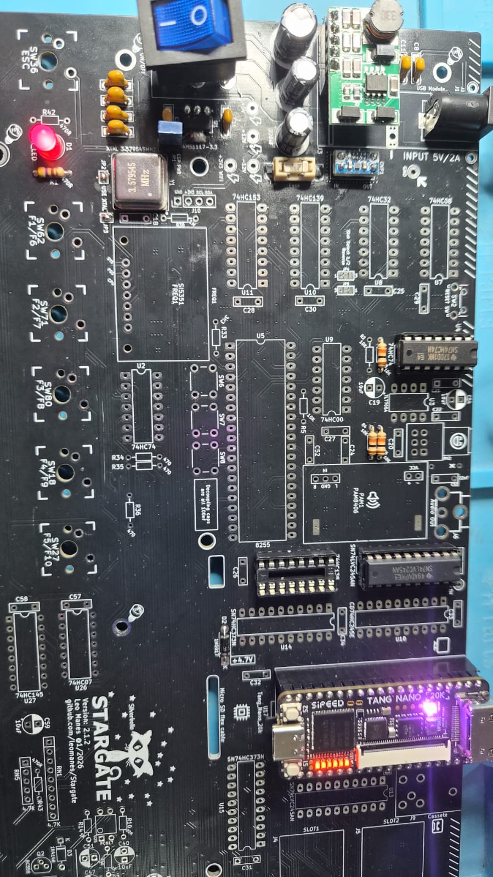
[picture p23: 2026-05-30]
build/imgs/basic_parts.jpeg

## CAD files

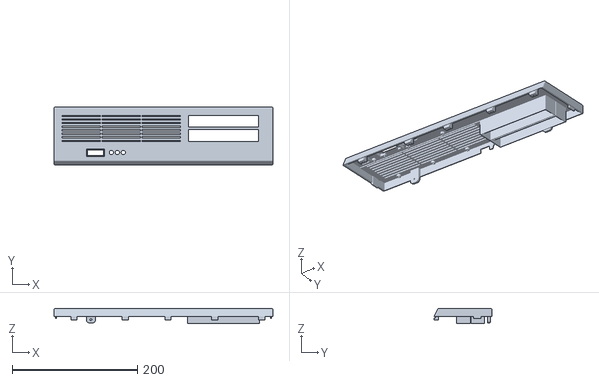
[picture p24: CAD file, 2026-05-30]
3d/deep/Stargate_top_deep_v1.1.STL
350.0 x 92.6 x 24.2

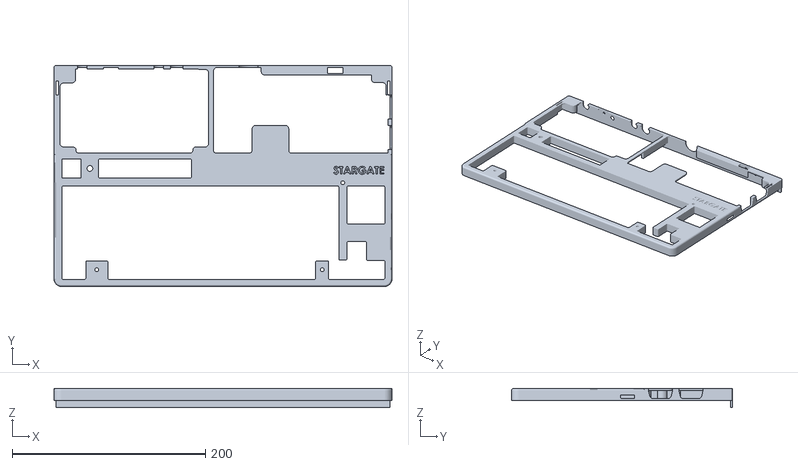
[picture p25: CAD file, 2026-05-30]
3d/slim/Stargate_deck_v1.1.STL
350.0 x 229.0 x 19.9

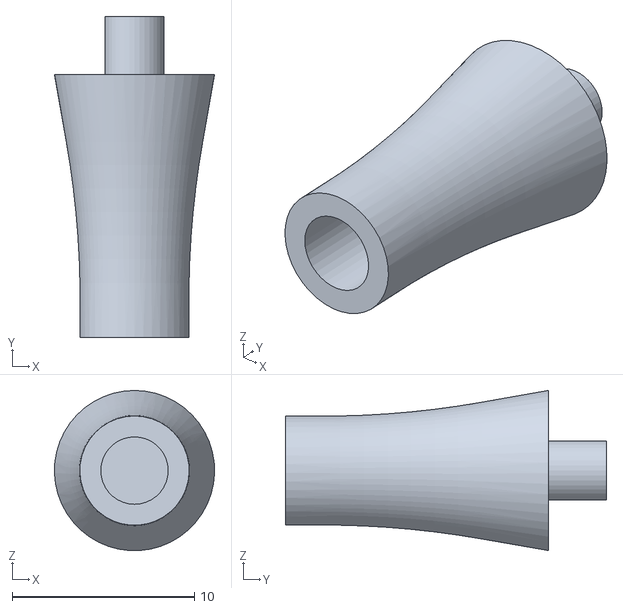
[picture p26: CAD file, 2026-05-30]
3d/deep/btn_support_v1.0.STL
8.80 x 17.6 x 8.79

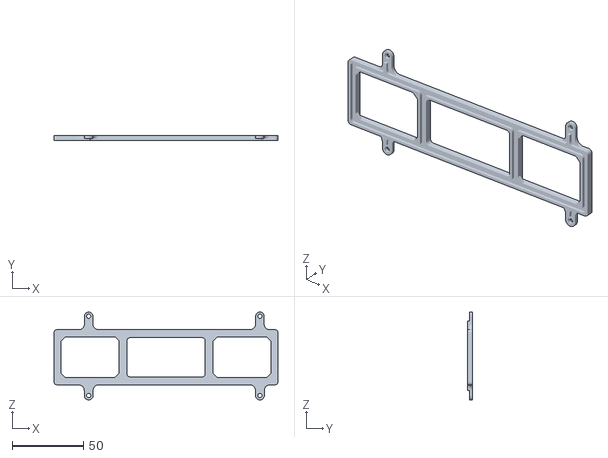
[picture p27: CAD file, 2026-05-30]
3d/deep/speaker holder_v2.STL
157.0 x 3.60 x 61.7

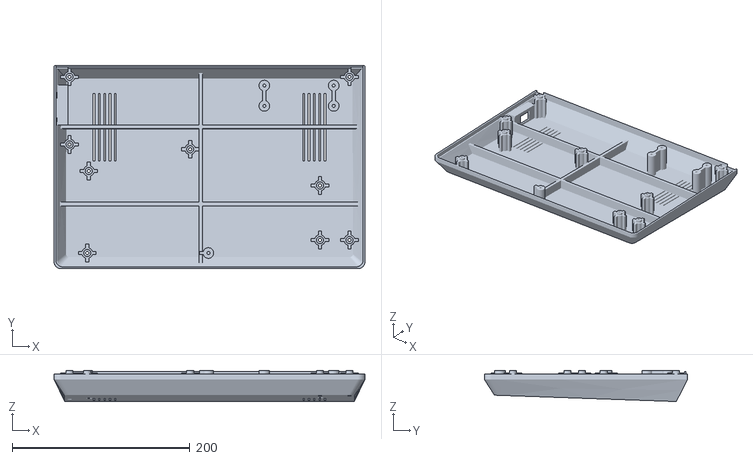
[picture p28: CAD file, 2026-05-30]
3d/deep/Stargate_base_deep_v1.0.STL
350.0 x 229.0 x 35.0

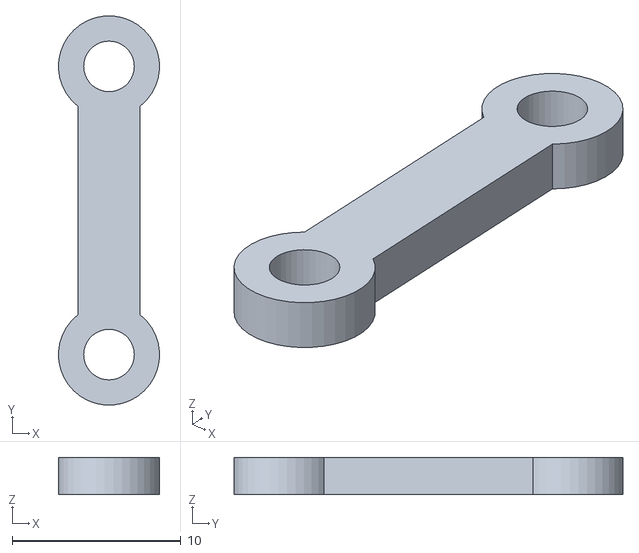
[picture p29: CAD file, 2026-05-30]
3d/slim/barra_oled_v1.0.STL
5.99 x 23.1 x 2.20

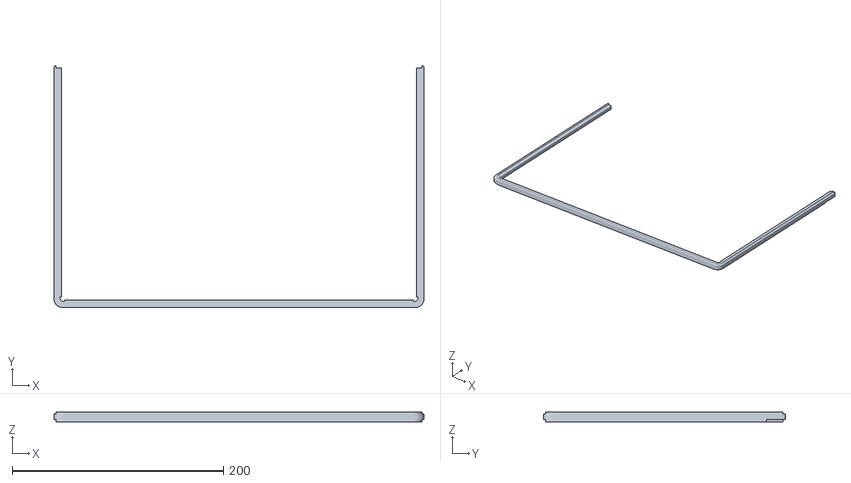
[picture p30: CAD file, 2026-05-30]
3d/deep/RGBframe_v1.0.STL
350.0 x 229.0 x 9.60

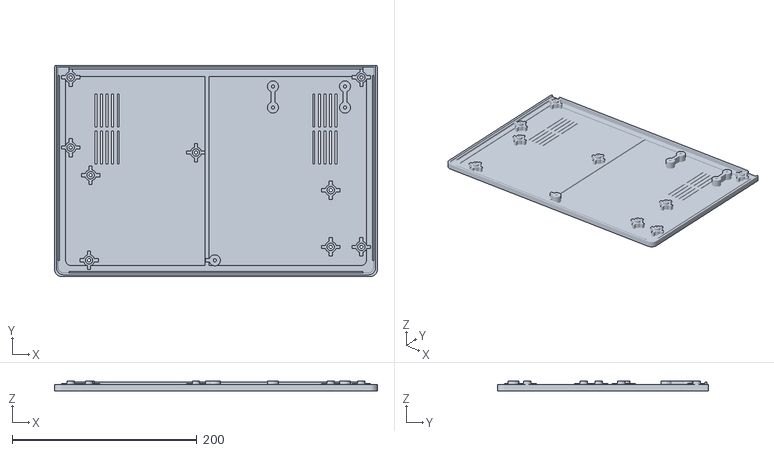
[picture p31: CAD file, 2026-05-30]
3d/slim/Stargate_base_slim_v1.3.STL
350.0 x 229.0 x 11.1

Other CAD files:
3d/slim/Stargate_top_slim_v1.1.STL

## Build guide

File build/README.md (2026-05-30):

<HTML>
<BODY>
<p><strong>THIS IS A TEMPORARY ASSEMBLY GUIDE. EXPECT IT TO CHANGE WITHOUT WARNINGS.</strong></p>
<p>&nbsp;</p>
<h2><strong>STARGATE BASIC VERSION:</strong></h2>
<p>The basic version does not have RGB leds, overclock capabilities or the oled screen.</p>
<p>Wi-Fi is optional.</p>
<p>&nbsp;</p>
<p><strong>STEP 1: POWER SUPPLY</strong></p>
<p>If you are going to assemble the basic version <u>without Wi-Fi</u>, you can skip U1, C16, C15, and the jumper JP1.</p>
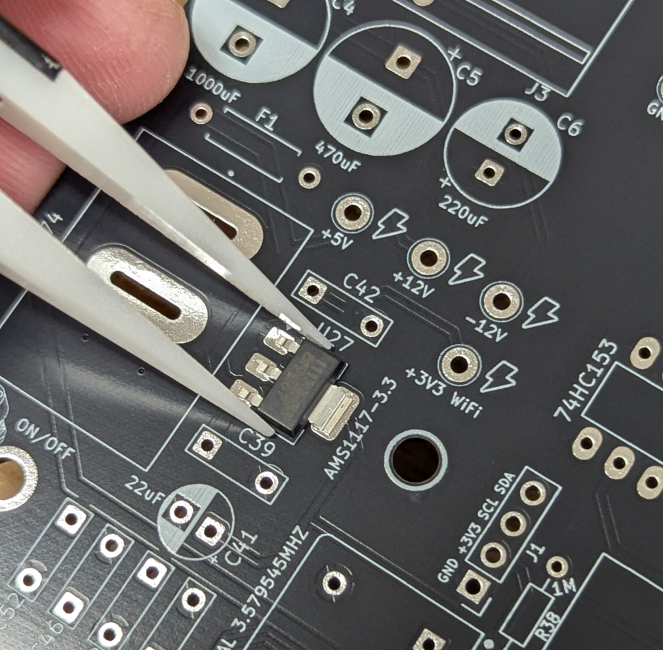
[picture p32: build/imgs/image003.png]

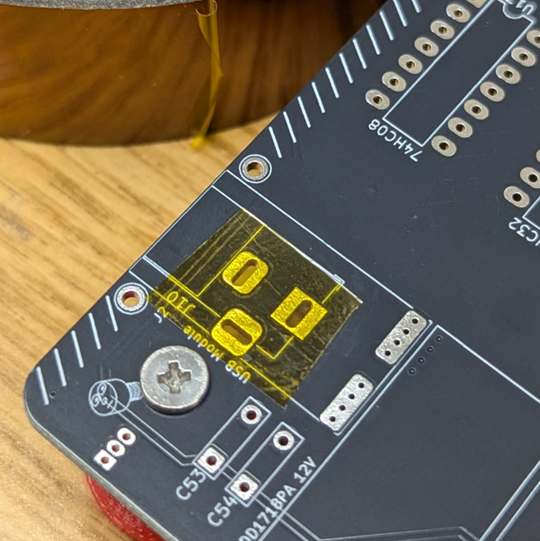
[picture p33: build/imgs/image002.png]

<p>If you are going to power the machine using an USB-C charger (recommended), add a piece of tape to cover the unused barrel jack pads.</p>
<p>Also, make sure your charger/adapter can supply at least 10W (2A) but 15W (3A) is encouraged.</p>
<p>Solder the PSU parts.</p>
<ul>
<li>U1 &ndash; AMS-1117-3.3</li>
<li>J1 OR J2 - (barrel jack or USB Decoy);</li>
<li>J3 - DC-DC converter (use straight pin headers);</li>
<li>OVP1 &ndash; Over Voltage Protection;</li>
<li>F1 &ndash; Fuse 1.5A;</li>
<li>D1 &ndash; Power Led ,RED 5mm;</li>
<li>R1 &ndash; 470R;</li>
<li>D2 &ndash; Diode 1N5817;</li>
<li>JP1 &ndash; Jumper (power ESP12F);</li>
<li>SW1 - Power Switch (do not insert the switch all the way down (only the tip of the terminals should be soldered. It will need to be adjusted later);</li>
<li>C4, C5, C6, C7, C8, C9, C10, C11, C12, C15, C16 &ndash; Capacitors.</li>
</ul>
<p>If you are <strong>not</strong> going to use carts that require +-12V you don&rsquo;t need the DC-DC converter J3 or the caps C5, C6, C8, C9, C11 and C12.</p>
<p><strong>Very few carts</strong> require these voltages and with the internal micro-SD, you probably will not even need to use the slots. Most CASIO machines don&rsquo;t have these voltages.</p>
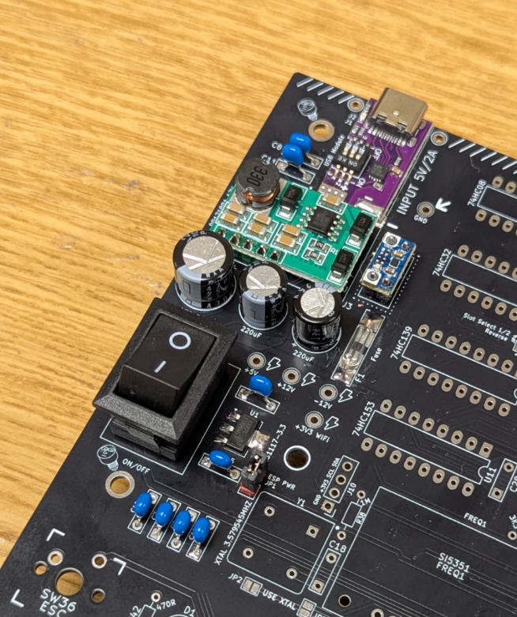
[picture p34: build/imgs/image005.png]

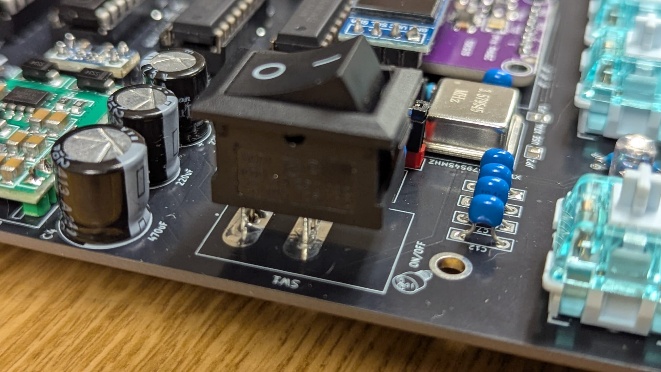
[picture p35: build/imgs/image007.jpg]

<p>USB Decoy configuration:</p>
<p>If using the Decoy USB, make sure it is configured to <strong>5V </strong>before powering up the machine:</p>
<p>Switches:</p>
<p>1 = ON</p>
<p>2 = OFF</p>
<p>3 = OFF</p>
<p>Once you configure it, do not touch it anymore. Cover it with a piece of electric tape if possible. <strong>An incorrect setting can damage your machine and even release the magic smoke.</strong></p>
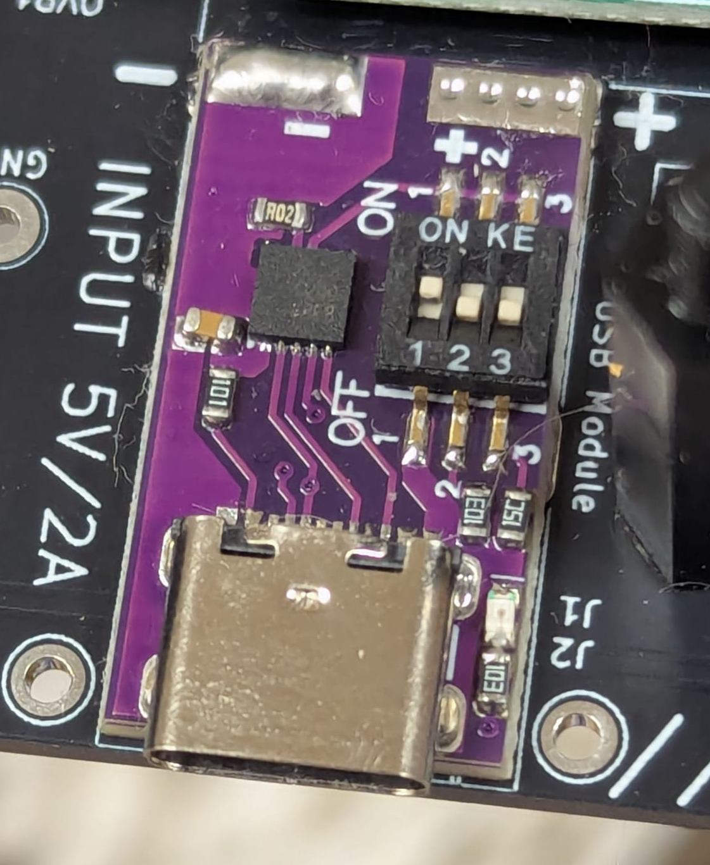
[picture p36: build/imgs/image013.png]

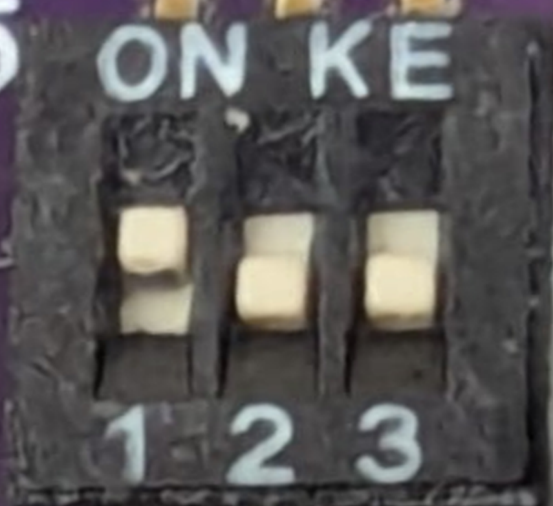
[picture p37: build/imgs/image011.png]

<p>&nbsp;</p>
<p><span style="color: #ff0000;">CRITICAL STEP</span></p>
<p>Pet your cat.</p>
<p>No cats? Adopt one from a shelter, they need a home. Specially the adult ones.</p>
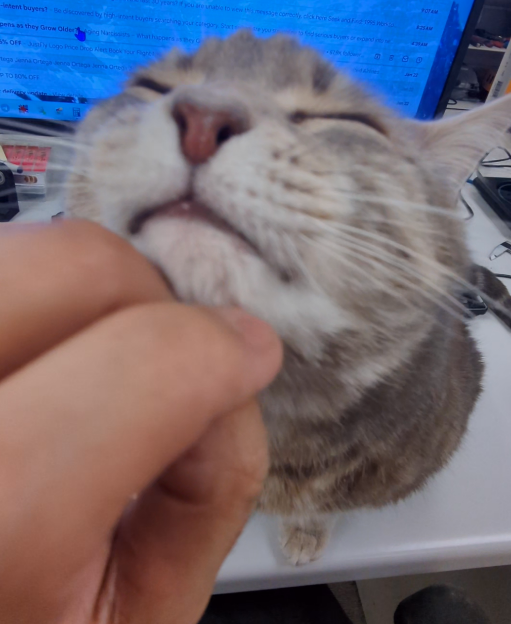
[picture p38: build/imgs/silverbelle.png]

<p>&nbsp;</p>
<p><strong>COLD TEST 1 - PSU</strong></p>
<p>Before continuing, make sure you test all the voltages using a multimeter.</p>
<p>Use the GND, +5V, +12V, -12V, 3.3V and 4.7V Test Points to verify if the voltages are correct. &nbsp;They are all marked on the board with a lightning bolt icon. Verify the 4.7V on D2 as well next to the Tang Nano (you should read above 4.7V).</p>
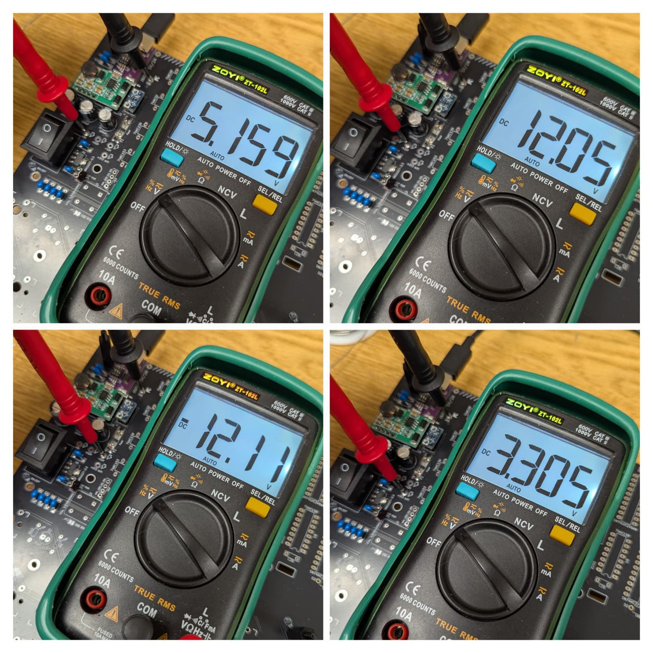
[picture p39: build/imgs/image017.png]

<p>&nbsp;</p>
<p><strong>STEP 2: CLOCK + TANG</strong></p>
<ul>
<li>Solder the oscillator Y1;</li>
<li>Close the solder jumpers JP2 and JP3 (right below the oscillator);</li>
<li>R3, R4, R6; Resistor;</li>
<li>U16, U4 &ndash; IC/sockets;</li>
<li>U17 &ndash; Socket + Tang Nano 20K *</li>
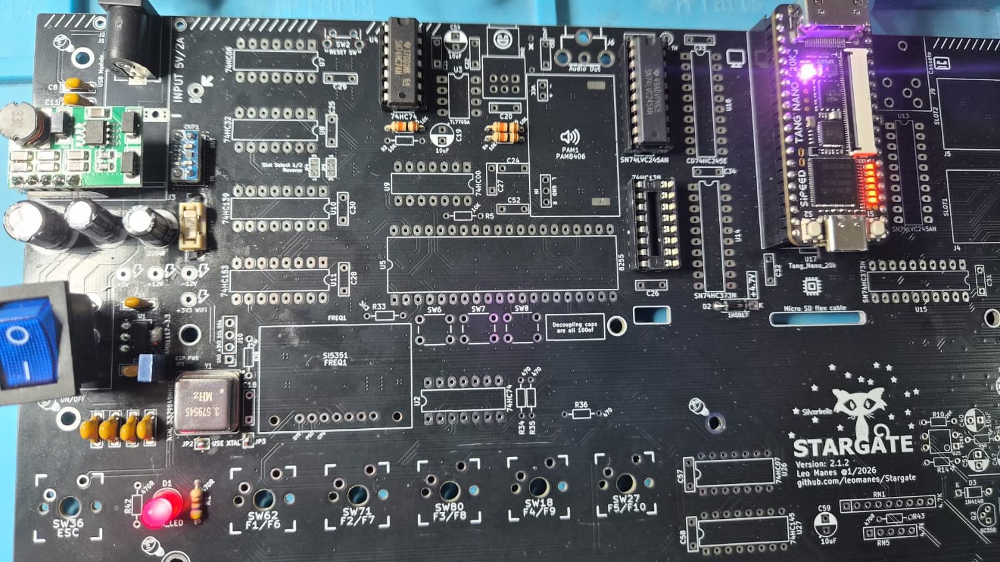
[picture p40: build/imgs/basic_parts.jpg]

</ul>
<p><br /> * <strong>Make sure you program your Tang Nano 20K before running the &ldquo;COLD TEST 2&rdquo;. Refer to Palver&rsquo;s GitHub page:</strong></p>
<p><strong>github.com/jabadiagm/MSXgoauldSD_tn20k</strong></p>
<p>&nbsp;</p>
<p><strong>COLD TEST 2 &ndash; BOOT SCREEN</strong></p>
<p>This test will verify if your Stargate can boot with the few basic parts.</p>
<p>Connect the Stargate to the HDMI monitor and run a boot test. You should boot and land on BASIC.</p>
<p>You should see the boot screen, but you won&rsquo;t be able to do anything else.</p>
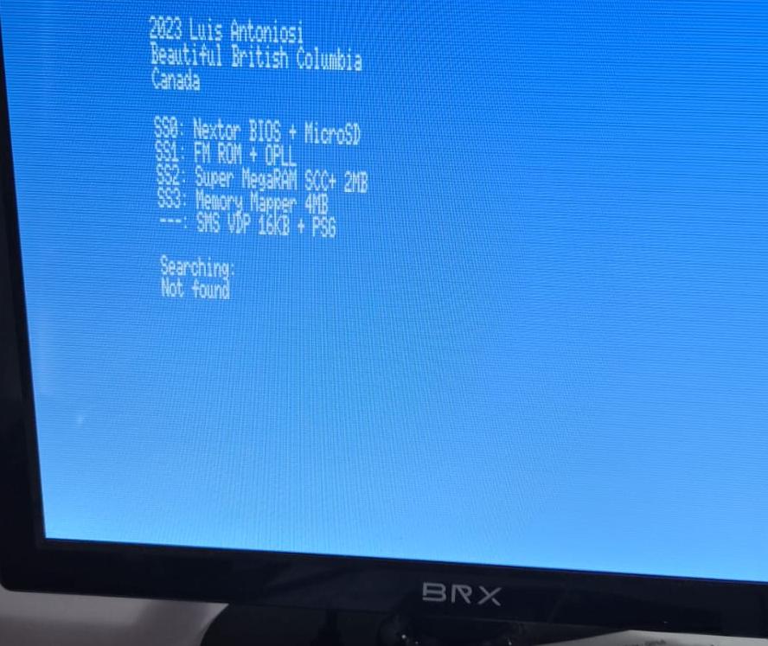
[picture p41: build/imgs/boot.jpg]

<p>&nbsp;</p>
<p><strong>STEP 3: GLUE LOGIC + CARTRIDGE SLOTS </strong></p>
<p>Now we are going to take care of the main glue logic and install the cartridge slots. Solder all the components listed below.</p>
<ul>
<li>C18, C19, C20, C21, C22, C23, C24, C25, C26, C27, C28, C29, C30, C31, C32, C33, C34, C35, C36 &ndash; Capacitors;</li>
<li>R2, R5 &ndash; Resistors;</li>
<li>RN1, RN2 &ndash; Resistor Networks;</li>
<li>U10, U11, U12, U13, U14, U15, U18, U3, U5, U6, U7, U8, U9 &ndash; IC/Sockets;</li>
<li>J4, J5 &ndash; Cartridge connectors;</li>
<li>SW2 &ndash; Reset microswitch.</li>
</ul>
<p><strong>&nbsp;</strong></p>
<p><strong>COLD TEST 3 &ndash; CART SLOT TEST</strong></p>
<p>First confirm the machine is booting to BASIC like in the previous COLD TEST 2.</p>
<p>Next, turn the machine on with a cartridge plugged in. Use a regular ROM cart if possible. Not all cartridges are compatible with Goa&rsquo;uld so try something simples first.</p>
<p>Test both slots.</p>
<p>( * the Gradiente Expert Tang firmware will not work for the Stargate. Slot 2 will fail among other issues. You need original's Palver's firmware)</p>
<p>&nbsp;</p>
<p><strong>STEP 4: JOYSTICK</strong></p>
<p>Solder the parts listed below:</p>
<ul>
<li>U2, U19, U20, U21, U22</li>
<li>C43 - C46</li>
<li>F2 - 0.5A</li>
<li>RN3 e RN4</li>
<li>J7, J8</li>
</ul>
<p>&nbsp;</p>
<p><strong>COLD TEST 4 &ndash; JOYSTICK</strong></p>
<p>Plug a MSX compatible controller on J7.&nbsp;(***make sure it is a MSX controller or you might blow a fuse or damage your Stargate***)</p>
<p>Boot Stargate with a cart and test UP,DOWN,LEFT,RIGHT, TRIGGER1,TRIGGER2 on both joystick ports. Make sure the game you select can use joysticks. Sofarun is also an option for testing.</p>
<p>&nbsp;</p>
<p><strong>STEP 5: ESP12F</strong></p>
<p>Solder the parts listed below:</p>
<ul>
<li>U24 - ESP12F</li>
<li>R37=220R for blue led | 470R for other colors) - modern led only. Avoid older used ones. They might prevent the ESP from booting.</li>
<li>R27 to R39</li>
<li>D4 - (flat side of the LED connected to the square pad)</li>
<li>C17 (laying down on the pcb)</li>
<li>SW3,SW4,SW5,SW6,SW7,SW8,SW9</li>
<li>J11</li>
<li>OLED screen (if you are not using a custom 3D case, use a header to plug the oled)</li>
</ul>
<p>&nbsp;Now program the ESP using a UART-USB adapter with dupont leads and the ESP Tools.</p>
<p><strong>&nbsp;</strong></p>
<p><strong>COLD TEST 5 &ndash; ESP12F</strong></p>
<p>Unplug the UART-USB, make sure JP1 is connected and turn on Stargate.</p>
<p>The oled needs to display STARGATE.</p>
<p>&nbsp;</p>
<p><strong>STEP 6: AUDIO MIXER</strong></p>
<p>Solder the parts listed below:</p>
<ul>
<li>R7-R13</li>
<li>C37-C41</li>
<li>J6</li>
<li>Q1</li>
<li>RV1 (audio feedback from the cassete and bluetooth while loading games)</li>
</ul>
<p>&nbsp;</p>
<p><strong>COLD TEST 6 &ndash; AUDIO MIXER</strong></p>
<p>Verify if audio is present on the RCA jack on the back of the machine. Test with a MSX1 ROM (for PSG) cart and a MSX pico running a SCC game (for cart Audio-IN).</p>
<p>Make sure the option "Disable PSG:" is set to OFF on the OLED settings. 
<p><strong>&nbsp;</strong></p>
</BODY>
</HTML>

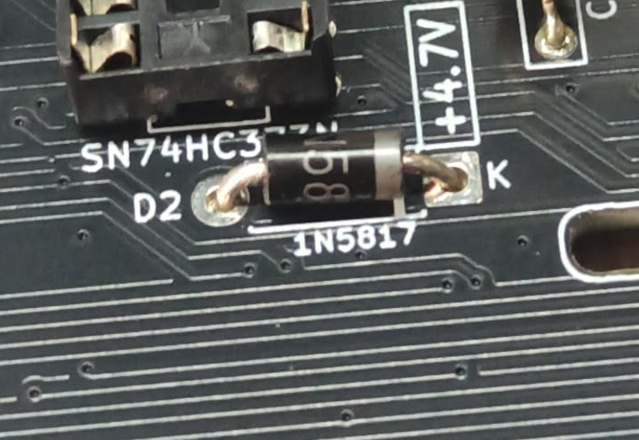
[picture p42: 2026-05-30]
build/imgs/image010.png

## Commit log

2026-06-13 Add files via upload
    latest v2.1.3
    [Keyboard.kicad_sch, MSX_Goauld.kicad_sch, RGBstrip.kicad_sch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]
2026-06-13 Update Readme with Gerbers location for v2.1.3
2026-06-13 Delete kicad/version v2.1.3 production/Goauld directory
    wrong location
    [G5V-1-DC5.stp]
2026-06-13 Add Stargate_v2.1.3.zip reference to Readme
    GERBERS
2026-06-13 Update README with version 2.1.3 details
    Version 2.1.3 available
    Kicad files released
2026-06-13 Revise daughter board note in README
    Updated note about the optional daughter board and its status.
